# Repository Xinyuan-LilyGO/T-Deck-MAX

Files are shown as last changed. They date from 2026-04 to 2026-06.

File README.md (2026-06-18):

<h1 align = "center">🏆T-Deck-MAX 🏆</h1>

|  [中文](./readme_cn.md) |  [English](./readme.md) |
| --- | --- |

<p> 
<!-- <img src="https://img.shields.io/badge/ESP—IDF-5.1.1-ff3034" height="20px"></a> -->
</a>
</a>
</p>



| Front | Back |
| :---: | :---: |
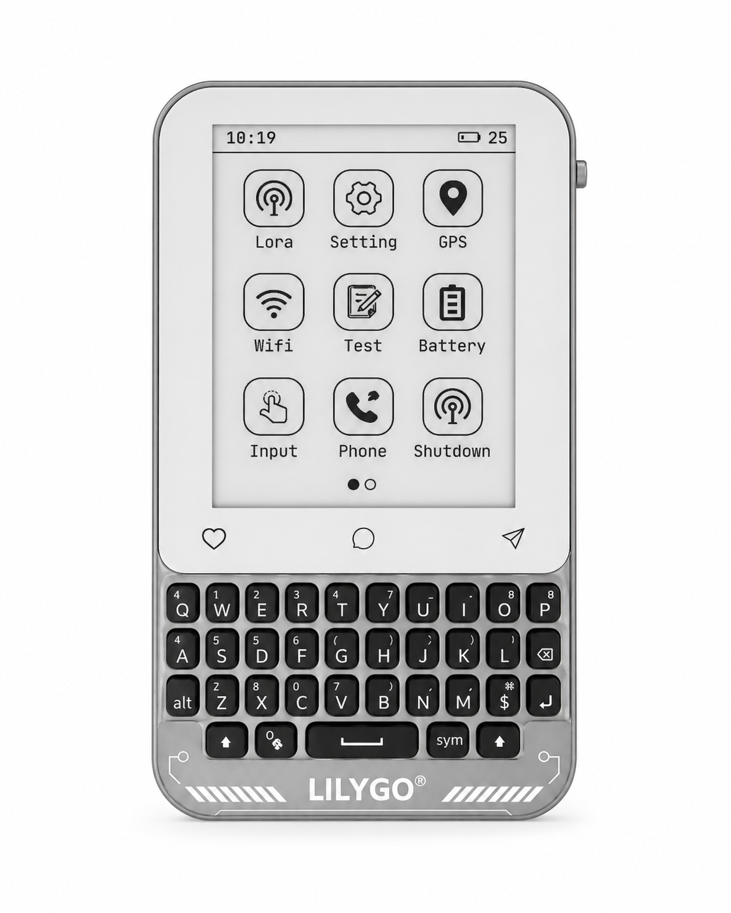
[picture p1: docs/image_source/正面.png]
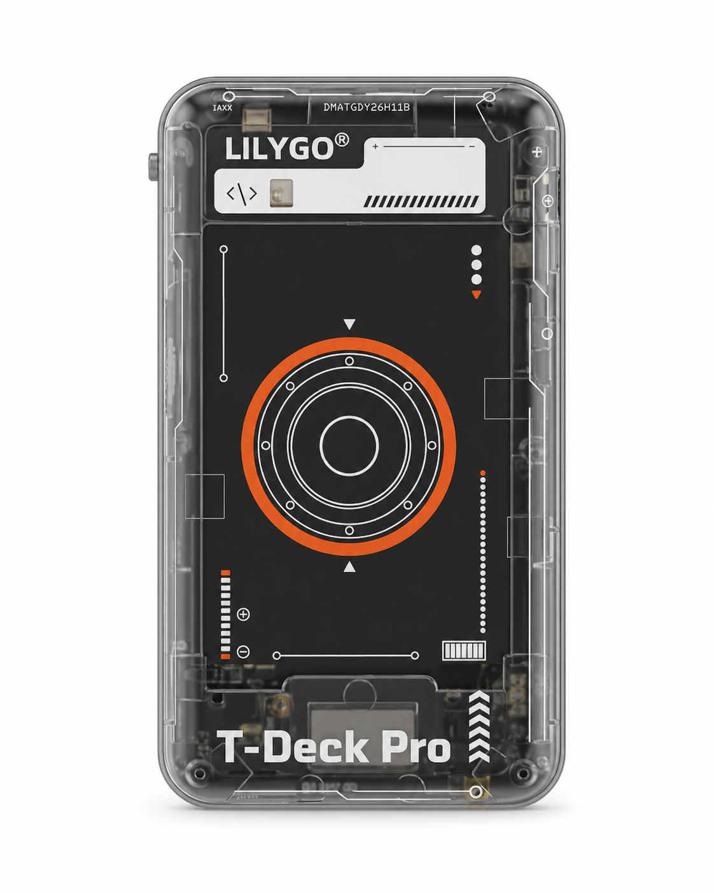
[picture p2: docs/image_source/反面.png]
|  |  |

## :zero: Version 🎁

**T-Deck-MAX** Revision Update Notes: 

- Added the XL9555 IO expansion chip 

- Remove the distinction between the audio version and the 4G version. Now, integrate the 4G (A7682E) and the audio (ES8311) onto a single board. 

- Add a LoRa antenna selection switch, controlled by XL9555 to select the internal or external antenna. The default is the internal antenna. 

- Add an audio channel output selection switch, and control the selection of using A7682E / ES8311 audio output through XL9555. 

- Add the vibration motor driving chip DRV2605

### 1、Version

How to confirm that your device is `T-Deck-MAX`?

Download the [WireScan](./firmware/examples/WireScan.bin) firmware and then open the serial port to confirm.

How to download the firmware? - [click me](./firmware/)

### 2、Where to buy.

[LilyGo Store](https://lilygo.cc/products/t-deck-pro)

## :one: Product 🎁

| Parameter | T-Deck-MAX |
| :---: | :---: |
| MCU | ESP32-S3 |
|  Flash / PSRAM | 16M / 8M |
| LoRa | SX1262 |
| GPS | MIA-M10Q |
| Display | GDEQ031T10 (320x240) |
| 4G-Module | A7682E |
| Battery Capacity | 3.7V-1400mAh |
| Battery Chip | SY6970 (0x6A), BQ27220 (0x55) |
| Audio | ES8311 (0x18) |
| Touch | CST3530 (0x1A) |
| Gyroscope | BHI260AP (0x28) |
| Keyboard | TCA8418 (0x34) |
| IO Expansion | XL9555 (0x20) |
| Motor | DRV2605 (0x5A) |

## Flashing Firmware 🎁

Before flashing firmware, connect the device to your computer, select the correct COM port, and put the board into download mode:

1. Press and hold the `BOOT` button.
2. Press and release the `RST` button on the back.
3. Release the `BOOT` button.

### 2.1. Use `LILYGO Spark` to Flash Firmware (Recommended)

- Download the tool from [LILYGO Spark](https://lilygo.cc/en-us/pages/lilygo-spark?srsltid=AfmBOoorTB7ptFu2LQNLRnoI2SA0zBGJTN6JpI9J3hmHEkKhBQSmeu0Y).

- Search for your device `T-Deck Max` and download the corresponding firmware.

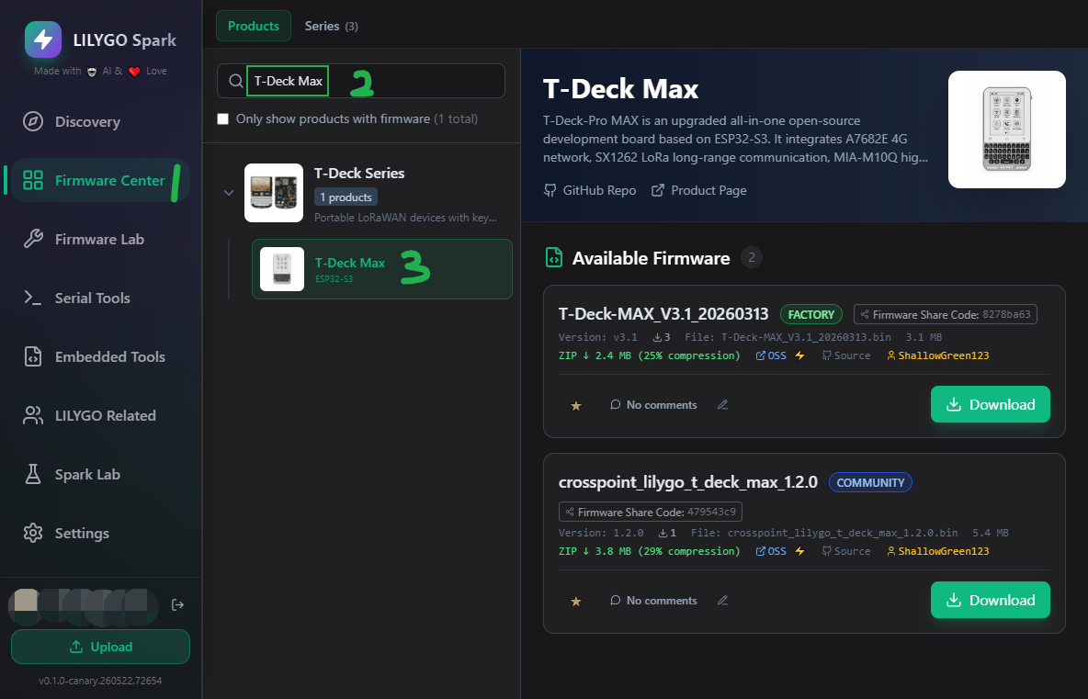
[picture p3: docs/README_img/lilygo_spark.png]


| Firmware | Note | Github |
| --- | --- | --- |
| T-Deck-MAX_xxxxx.bin | Factory program<br> | - |
| crosspoint_lilygo_t_deck_max_xxxx.bin | Reader program | [TDeckMax-Reader](https://github.com/ShallowGreen123/TDeckMax-Reader) |

## :two: Module 🎁

### 1. A7682E

A7682E https://en.simcom.com/product/A7682E.html

A7682E is the LTE Cat 1 module that supports wirelesscommunication modes of LTE-FDD/GSM/GPRS/EDGE.   It supports maximum 10Mbps downlink rate and 5Mbps uplink rate. A7682E supports multiple built-in network protocols.

Insert the SIM card and it supports calls, text messages and internet access.

Test the functionality of the A7682E using [`examples/A7682E/test_AT`](https://github.com/Xinyuan-LilyGO/T-Deck-Pro/tree/master/examples/A7682E/test_AT)

Control Via AT Commands
~~~
Frequency Bands LTE-FDD B1/B3/B5/B7/B8/B20
GSM/GPRS/EDGE 900/1800 MHz
Supply Voltage 3.4V ~ 4.2V, Typ: 3.8V
LTE Cat 1   (Uplink up to 5Mbps, Downlink up to10Mbps)
EDGE        (Uplink/Downlink up to 236.8Kbps)
GPRS        (Uplink/Downlink up to 85.6Kbps)
Firmware update via USB/FOTA
Support language calls
Support sending and receiving SMS messages
network protocols (TCP/IP/IPV4/IPV6/Multi-PDP/FTP/FTPS/HTTP/HTTPS/DNS)
RNDIS/PPP/ECM
SSL
~~~
❗ Note: The speakers of A7682E and ES8311 are shared. Set `IO12` of `XL9555` to `HIGH` and output the audio of A7682E.
The sound is too weak. Set `IO06` of the `XL9555` to `HIGH` to enable the power amplifier. [example](./examples/A7682E/test_AT/test_AT.ino)

### 2. ES8311

❗ Note: The speakers of A7682E and ES8311 are shared. Set `IO12` of `XL9555` to `LOW` and output the audio of ES8311.
The sound is too weak. Set `IO06` of the `XL9555` to `HIGH` to enable the power amplifier.

### 3. LoRa

❗ Note:
| When using the internal antenna, set `IO04` of `XL9555` to `HIGH`.<br><br>When using an external antenna, set `IO04` of `XL9555` to `LOW`.<br><br>The current repository uses `HIGH` for internal and `LOW` for external antenna selection. |
| :---------------------------------------------------------------------------------------------------------------------------------------------------------------------------------------------------------------------------------- |
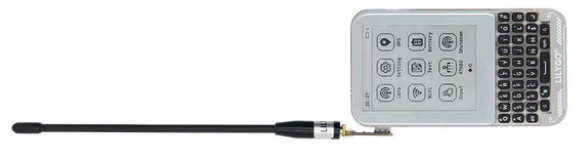
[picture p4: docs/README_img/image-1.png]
|  |

## :three: Examples 🎁

The following lists all examples to help you quickly get started with each module:

| Example | Path | Description |
| :--- | :--- | :--- |
| **WireScan** | `examples/WireScan/` | I2C device scanner, open serial monitor after flashing to verify modules |
| **test_wifi** | `examples/test_wifi/` | WiFi connection test |
| **test_BHI260AP** | `examples/test_BHI260AP/` | Gyroscope (BHI260AP) test |
| **test_GPS** | `examples/test_GPS/` | GPS (MIA-M10Q) module test |
| **keypad** | `examples/keypad/` | Keyboard input test |
| **XL9555/read** | `examples/XL9555/read/` | IO expansion chip read example |
| **XL9555/write** | `examples/XL9555/write/` | IO expansion chip write example |
| **Elink_paper/touch** | `examples/Elink_paper/touch/` | Touch screen basic test |
| **Elink_paper/display** | `examples/Elink_paper/display/` | E-paper screen display example |
| **Elink_paper/test_lvgl** | `examples/Elink_paper/test_lvgl/` | LVGL graphics library example |
| **Elink_paper/GDEQ031T10_Arduino** | `examples/Elink_paper/GDEQ031T10_Arduino/` | E-paper Arduino library driver example |
| **LoRa_sx1262/lora_send** | `examples/LoRa_sx1262/lora_send/` | LoRa send example |
| **LoRa_sx1262/lora_recv** | `examples/LoRa_sx1262/lora_recv/` | LoRa receive example |
| **A7682E/test_AT** | `examples/A7682E/test_AT/` | 4G module AT command test |
| **ES8311/playWAV** | `examples/ES8311/playWAV/` | WAV audio playback example |
| **ES8311/playFormSD** | `examples/ES8311/playFormSD/` | Audio playback from TF card example |
| **battery/bq25896** | `examples/battery/bq25896/` | Battery management IC BQ25896 test |
| **battery/bq27220** | `examples/battery/bq27220/` | Battery fuel gauge BQ27220 test |
| **battery/sy6974** | `examples/battery/sy6974/` | Battery charging IC SY6974 test |
| **motor/basic** | `examples/motor/basic/` | Vibration motor basic example |
| **motor/audio** | `examples/motor/audio/` | Vibration motor audio feedback example |
| **motor/realtime** | `examples/motor/realtime/` | Vibration motor real-time control example |
| **motor/complex** | `examples/motor/complex/` | Vibration motor complex pattern example |
| **tf_card** | `examples/tf_card/` | TF card read/write test |
| **eng_test** | `examples/eng_test/` | Full system functionality test |

### Quick Start Guide

1. **First use**: Flash `WireScan` firmware first, verify I2C communication is normal
2. **Display related**: Start with `Elink_paper/touch` or `Elink_paper/display`
3. **Wireless communication**: WiFi test uses `test_wifi`, LoRa uses `lora_send`/`lora_recv`
4. **4G communication**: Use `A7682E/test_AT` to test AT commands
5. **Audio functions**: Try `ES8311/playWAV` first to play WAV files
6. **Battery related**: Use `battery/bq25896` to check battery status

## :four: Quick Start 🎁

🟢 PlatformIO is recommended because these examples were developed on it. 🟢 

### 1、PlatformIO

1. Install [Visual Studio Code](https://code.visualstudio.com/) and [Python](https://www.python.org/), and clone or download the project;
2. Search for the `PlatformIO` plugin in the `VisualStudioCode` extension and install it;
3. After the installation is complete, you need to restart `VisualStudioCode`
4. After opening this project, PlatformIO will automatically download the required tripartite libraries and dependencies, the first time this process is relatively long, please wait patiently;
5. After all the dependencies are installed, you can open the `platformio.ini` configuration file, uncomment in `example` to select a routine, and then press `ctrl+s` to save the `.ini` configuration file;
6. Click :ballot_box_with_check: under VScode to compile the project, then plug in USB and select COM under VScode;
7. Finally, click the :arrow_right:  button to download the program to Flash;

### 2、Arduino IDE

1. Install [Arduino IDE](https://www.arduino.cc/en/software)

2. Copy all files under `this project/lib/` and paste them into the Arduino library path (generally `C:\Users\YourName\Documents\Arduino\libraries`);

3. Open the Arduino IDE and click `File->Open` in the upper left corner to open an example in `this project/example/xxx/xxx.ino` under this item;

4. Then configure Arduino. After the configuration is completed in the following way, you can click the button in the upper left corner of Arduino to compile and download;

| Arduino IDE Setting | Value                              |
| --- | --- |
| Board | ***ESP32S3 Dev Module*** |
| Port | Your port                          |
| USB CDC On Boot | Enable |
| CPU Frequency | 240MHZ(WiFi)                       |
| Core Debug Level | None                               |
| USB DFU On Boot | Disable                            |
| Erase All Flash Before Sketch Upload | Disable                            |
| Events Run On | Core1                              |
| Flash Mode | QIO 80MHZ                          |
| Flash Size | **16MB(128Mb)**                    |
| Arduino Runs On | Core1                              |
| USB Firmware MSC On Boot | Disable                            |
| Partition Scheme | **16M Flash(3M APP/9.9MB FATFS)**  |
| PSRAM | **QSPI PSRAM**                      |
| Upload Mode | **UART0/Hardware CDC**             |
| Upload Speed | 921600                             |
| USB Mode | **CDC and JTAG**                   |

## :five: Pins 🎁

Board-level macros are now centralized in a single public header:

- [`lib/TDeckMaxBoard/src/TDeckMaxBoard.h`](./lib/TDeckMaxBoard/src/TDeckMaxBoard.h)

Use it directly in examples:

~~~c
#include <TDeckMaxBoard.h>
~~~

Pin Mapping : [pinmap](./docs/pinmap.md)

## :six: Test 🎁

Sleep power consumption.

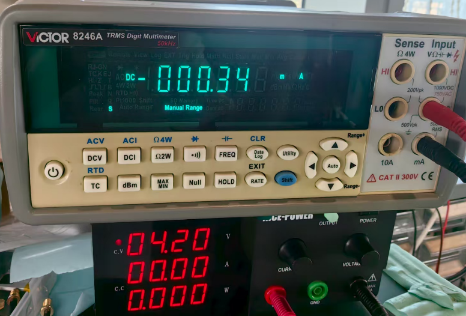
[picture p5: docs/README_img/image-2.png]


## :seven: FAQ 🎁

## :eight: Schematic & 3D 🎁

For more information, see the `./hardware` directory.

----

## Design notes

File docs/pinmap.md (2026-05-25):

# T-Deck Pro Max Pin Map (V0.1 / 2025-09-11)
> This document is organized from `hardware/T-Deck Pro Max V0.1 25-09-11/T-Deck Pro Max V0.1 25-09-11.pdf`, and cross-checked against the current repository macros in `lib/TDeckMaxBoard/src/TDeckMaxBoard.h`, `readme.md`, and `readme_cn.md`.
> It is grouped by module. Some schematic net names are labeled from the peripheral's point of view, such as `GPS_TX`, `7682_RXD`, and `I2S_DSDIN`. Where that matters, both the schematic name and the repo macro are noted.

## 1. MCU And Shared Buses

| Function | Current Macro / Preferred Name | GPIO | Source | Notes |
| --- | --- | --- | --- | --- |
| Shared I2C SDA | `BOARD_I2C_SDA` | 13 | Schematic Page 1/4/7/8 | Shared by the main board I2C bus |
| Shared I2C SCL | `BOARD_I2C_SCL` | 14 | Schematic Page 1/4/7/8 | Shared by the main board I2C bus |
| Shared SPI SCK | `BOARD_SPI_SCK` | 36 | Schematic Page 3/4/6 | Shared by EPD, TF, and SX1262 |
| Shared SPI MOSI | `BOARD_SPI_MOSI` | 33 | Schematic Page 3/4/6 | Shared by EPD, TF, and SX1262 |
| Shared SPI MISO | `BOARD_SPI_MISO` | 47 | Schematic Page 3/6 | Shared by TF and SX1262 |
| BOOT | `BOARD_BOOT_PIN` | 0 | Schematic Page 2 | Boot button |

## 2. XL9555 Expansion IO

I2C address: `0x20`.

`BOARD_XL9555_INT` is currently fixed to `-1`, because the XL9555 `INT` pin is not connected to any ESP32-S3 pin.

| XL9555 | Current Macro / Preferred Name | Board Net | Direction | Source | Notes |
| --- | --- | --- | --- | --- | --- |
| P00 | `BOARD_XL9555_00_6609_EN` | `6609_EN` | Output | Schematic Page 1/7 | Enables A7682E power |
| P01 | `BOARD_XL9555_01_LORA_EN` | `LORA_EN` | Output | Schematic Page 3/7 | Enables SX1262 power |
| P02 | `BOARD_XL9555_02_GPS_EN` | `GPS_EN` | Output | Schematic Page 3/7 | Enables MIA-M10Q power |
| P03 | `BOARD_XL9555_03_1V8_EN` | `1V8_EN` | Output | Schematic Page 4/7 | Enables BHI260AP 1.8 V rail |
| P04 | `BOARD_XL9555_04_LORA_SEL` | `LORA_SEL` | Output | Schematic Page 3/7 | `HIGH` = internal antenna, `LOW` = external antenna |
| P05 | `BOARD_XL9555_05_MOTOR_EN` | `M_EN` | Output | Schematic Page 4/7 | DRV2605 power / enable |
| P06 | `BOARD_XL9555_06_AMPLIFIER` | `SHUTDOWM` | Output | Schematic Page 7/8 | Power amplifier enable; the schematic net is spelled `SHUTDOWM` |
| P07 | `BOARD_XL9555_07_TOUCH_RST` | `T_RST` | Output | Schematic Page 4/7 | Touch reset, active low |
| P10 | `BOARD_XL9555_10_PWRKEY_EN` | `PWRKEY_EN` | Output | Schematic Page 5/7 | A7682E `PWRKEY` control |
| P11 | `BOARD_XL9555_11_KEY_RST` | `KEY_RST` | Output | Schematic Page 7 | Keyboard reset, active low |
| P12 | `BOARD_XL9555_12_AUDIO_SEL` | `AUDIO_SEL` | Output | Schematic Page 7/8 | `HIGH = A7682E`, `LOW = ES8311` |
| P13 | `BOARD_XL9555_13` | NC | - | Schematic Page 7 | Reserved in the current repo |
| P14 | `BOARD_XL9555_14` | NC | - | Schematic Page 7 | Reserved in the current repo |
| P15 | `BOARD_XL9555_15` | NC | - | Schematic Page 7 | Reserved in the current repo |
| P16 | `BOARD_XL9555_16` | NC | - | Schematic Page 7 | Reserved in the current repo |
| P17 | `BOARD_XL9555_17` | NC | - | Schematic Page 7 | Reserved in the current repo |

## 3. EPD Display

| Function | Current Macro / Preferred Name | GPIO / Mapping | Source | Notes |
| --- | --- | --- | --- | --- |
| EPD DC | `BOARD_EPD_DC` | GPIO35 | Schematic Page 4 | Schematic net name: `LCD_D/C` |
| EPD CS | `BOARD_EPD_CS` | GPIO34 | Schematic Page 4 | Schematic net name: `LCD_CS` |
| EPD BUSY | `BOARD_EPD_BUSY` | GPIO37 | Schematic Page 4 | Schematic net name: `LCD_BUSY` |
| EPD RST | `BOARD_EPD_RST` | GPIO9 | Schematic Page 4 | Schematic net name: `LCD_RST` |
| EPD SCK | `BOARD_EPD_SCK` | GPIO36 | Schematic Page 4 | Shared SPI bus |
| EPD MOSI | `BOARD_EPD_MOSI` | GPIO33 | Schematic Page 4 | Shared SPI bus |
| EPD frontlight PWM | `BOARD_EPD_BL` | GPIO41 | Schematic Page 4 | Schematic net name: `BL_PWM` |

## 4. Touch CST328

I2C address: `0x1A`.

| Function | Current Macro / Preferred Name | GPIO / Mapping | Source | Notes |
| --- | --- | --- | --- | --- |
| I2C SDA | `BOARD_TOUCH_SDA` | GPIO13 | Schematic Page 4 | Shared I2C bus |
| I2C SCL | `BOARD_TOUCH_SCL` | GPIO14 | Schematic Page 4 | Shared I2C bus |
| INT | `BOARD_TOUCH_INT` | GPIO12 | Schematic Page 4 | CST328 interrupt |
| RST | `BOARD_TOUCH_RST` | `XL9555 P07` | Schematic Page 4/7 | Board net `T_RST`; not a direct ESP32 GPIO |

## 5. Keyboard TCA8418

I2C address: `0x34`.

| Function | Current Macro / Preferred Name | GPIO / Mapping | Source | Notes |
| --- | --- | --- | --- | --- |
| I2C SDA | `BOARD_KEYBOARD_SDA` | GPIO13 | Schematic Page 7 | Shared I2C bus |
| I2C SCL | `BOARD_KEYBOARD_SCL` | GPIO14 | Schematic Page 7 | Shared I2C bus |
| INT | `BOARD_KEYBOARD_INT` | GPIO15 | Schematic Page 7 | TCA8418 interrupt |
| Backlight PWM | `BOARD_KEYBOARD_LED` | GPIO42 | Schematic Page 7 | Schematic net name: `LED_PWM` |
| RST | `BOARD_KEYBOARD_RST` | `XL9555 P11` | Schematic Page 7 | Board net `KEY_RST`, active low |

## 6. IMU BHI260AP

I2C address: `0x28`.

| Function | Current Macro / Preferred Name | GPIO / Mapping | Source | Notes |
| --- | --- | --- | --- | --- |
| I2C SDA | `BOARD_GYROSCOPDE_SDA` | GPIO13 | Schematic Page 4 | Shared I2C bus |
| I2C SCL | `BOARD_GYROSCOPDE_SCL` | GPIO14 | Schematic Page 4 | Shared I2C bus |
| INT | `BOARD_GYROSCOPDE_INT` | GPIO21 | Schematic Page 4 | Schematic net name: `HIRQ` |
| RST | `BOARD_GYROSCOPDE_RST` | `-1` | Schematic Page 4 | Reset is not wired |
| Power enable | `BOARD_XL9555_03_1V8_EN` | `XL9555 P03` | Schematic Page 4/7 | `HIGH` powers the IMU rail |

## 7. Motor DRV2605

I2C address: `0x5A`.

| Function | Current Macro / Preferred Name | GPIO / Mapping | Source | Notes |
| --- | --- | --- | --- | --- |
| I2C SDA | `BOARD_MOTOR_SDA` | GPIO13 | Schematic Page 4 | Shared I2C bus |
| I2C SCL | `BOARD_MOTOR_SCL` | GPIO14 | Schematic Page 4 | Shared I2C bus |
| Power / enable | `BOARD_MOTOR_EN` | `XL9555 P05` | Schematic Page 4/7 | Board net `M_EN` |

## 8. LoRa SX1262

| Function | Current Macro / Preferred Name | GPIO / Mapping | Source | Notes |
| --- | --- | --- | --- | --- |
| SCK | `BOARD_LORA_SCK` | GPIO36 | Schematic Page 3 | Shared SPI bus |
| MOSI | `BOARD_LORA_MOSI` | GPIO33 | Schematic Page 3 | Shared SPI bus |
| MISO | `BOARD_LORA_MISO` | GPIO47 | Schematic Page 3 | Shared SPI bus |
| CS | `BOARD_LORA_CS` | GPIO3 | Schematic Page 3 | Module `NSS` |
| RST | `BOARD_LORA_RST` | GPIO4 | Schematic Page 3 | Module `NRESET` |
| IRQ | `BOARD_LORA_INT` | GPIO5 | Schematic Page 3 | Module `DIO1` |
| BUSY | `BOARD_LORA_BUSY` | GPIO6 | Schematic Page 3 | Module `BUSY` |
| Power enable | `BOARD_XL9555_01_LORA_EN` | `XL9555 P01` | Schematic Page 3/7 | `HIGH` powers the module |
| Antenna select | `BOARD_XL9555_04_LORA_SEL` | `XL9555 P04` | Schematic Page 3/7 | Current repo convention: `HIGH` = internal, `LOW` = external |

## 9. GPS MIA-M10Q

| Function | Current Macro / Preferred Name | GPIO / Mapping | Source | Notes |
| --- | --- | --- | --- | --- |
| PPS | `BOARD_GPS_PPS` | GPIO1 | Schematic Page 3 | Schematic net name: `PPS` |
| Module TX -> MCU RX | `GPS_TX` / `BOARD_GPS_RXD` | GPIO2 | Schematic Page 3 | Schematic net names are from the GPS module point of view |
| Module RX <- MCU TX | `GPS_RX` / `BOARD_GPS_TXD` | GPIO16 | Schematic Page 3 | Schematic net names are from the GPS module point of view |
| Power enable | `BOARD_XL9555_02_GPS_EN` | `XL9555 P02` | Schematic Page 3/7 | `HIGH` powers the module |

## 10. 4G Modem A7682E

| Function | Current Macro / Preferred Name | GPIO / Mapping | Source | Notes |
| --- | --- | --- | --- | --- |
| RI | `BOARD_A7682E_RI` | GPIO7 | Schematic Page 2/5 | Module `RI` |
| DTR | `BOARD_A7682E_ITR` / `BOARD_A7682E_DTR` | GPIO8 | Schematic Page 2/5 | The current repo interprets this signal as `DTR` |
| Module RXD | `7682_RXD` / `BOARD_A7682E_RXD` | GPIO10 | Schematic Page 2/5 | Net name is labeled from the modem side |
| Module TXD | `7682_TXD` / `BOARD_A7682E_TXD` | GPIO11 | Schematic Page 2/5 | Net name is labeled from the modem side |
| Power enable | `BOARD_XL9555_00_6609_EN` | `XL9555 P00` | Schematic Page 1/7 | A7682E main power rail enable |
| `PWRKEY` control | `BOARD_A7682E_PWRKEY` / `BOARD_XL9555_10_PWRKEY_EN` | `XL9555 P10` | Schematic Page 5/7 | Board net `PWRKEY_EN` |

## 11. TF Card

| Function | Current Macro / Preferred Name | GPIO | Source | Notes |
| --- | --- | --- | --- | --- |
| SD CS | `BOARD_SD_CS` | 48 | Schematic Page 2/6 | Shares SPI with EPD and LoRa |
| SD SCK | `BOARD_SD_SCK` | 36 | Schematic Page 3/6 | Shared SPI bus |
| SD MOSI | `BOARD_SD_MOSI` | 33 | Schematic Page 3/6 | Shared SPI bus |
| SD MISO | `BOARD_SD_MISO` | 47 | Schematic Page 3/6 | Shared SPI bus |

## 12. Audio ES8311

I2C address: `0x18`.

| Function | Current Macro / Preferred Name | GPIO / Mapping | Source | Notes |
| --- | --- | --- | --- | --- |
| I2C SDA | `BOARD_ES8311_SDA` | GPIO13 | Schematic Page 8 | Shared I2C bus |
| I2C SCL | `BOARD_ES8311_SCL` | GPIO14 | Schematic Page 8 | Shared I2C bus |
| I2S MCLK | `BOARD_ES8311_MCLK` | GPIO38 | Schematic Page 8 | `I2S_MCLK` |
| I2S BCLK / SCLK | `BOARD_ES8311_SCLK` | GPIO39 | Schematic Page 8 | `I2S_SCLK` |
| I2S LRCK | `BOARD_ES8311_LRCK` | GPIO18 | Schematic Page 8 | `I2S_LRCK` |
| ES8311 `ASDOUT` -> ESP32 DIN | `BOARD_ES8311_ASDOUT` | GPIO40 | Schematic Page 8 | Current repo macro naming follows the existing code convention |
| ESP32 DOUT -> ES8311 `DSDIN` | `BOARD_ES8311_DSDIN` | GPIO17 | Schematic Page 8 | Current repo macro naming follows the existing code convention |
| Power amp enable | `BOARD_XL9555_06_AMPLIFIER` | `XL9555 P06` | Schematic Page 7/8 | `HIGH` enables the amplifier |
| Audio route select | `BOARD_XL9555_12_AUDIO_SEL` | `XL9555 P12` | Schematic Page 7/8 | `HIGH = A7682E`, `LOW = ES8311` |

> Note: the current repo uses the long-standing `BOARD_ES8311_ASDOUT/DSDIN` macro names from the code side. If you read the ES8311 pin names strictly from the codec side, the apparent data directions can look reversed, so always verify the signal direction when refactoring or wiring new code.

## 13. I2C Address Table

| Device | Address | Source | Notes |
| --- | --- | --- | --- |
| ES8311 | `0x18` | Schematic Page 8 | Audio codec |
| CST328 | `0x1A` | `readme*.md` | Touch controller |
| XL9555 | `0x20` | Schematic Page 7 | IO expander |
| BHI260AP | `0x28` | Schematic Page 4 | IMU |
| TCA8418 | `0x34` | Schematic Page 7 | Keyboard matrix controller |
| BQ27220 | `0x55` | Schematic Page 1 | Fuel gauge |
| DRV2605 | `0x5A` | Schematic Page 4 | Vibration motor driver |
| BQ25896 | `0x6B` | Schematic Page 1 | Charger, now deprecated |
| SY6970 | `0x6A` | Schematic Page 1 | Charger |

Note: `BQ25896` was later replaced. Newer `T-Deck-MAX` boards use `SY6970`.

## 14. Current Codebase Notes

- `BOARD_A7682E_ITR` should be understood as `DTR`. The current public header also provides the alias `BOARD_A7682E_DTR`.
- GPS UART, A7682E UART, and ES8311 I2S naming still mix peripheral-side and ESP32-side viewpoints in different places. When writing new code, spell out the direction explicitly.
- Board-level macros are now centralized in `lib/TDeckMaxBoard/src/TDeckMaxBoard.h`.

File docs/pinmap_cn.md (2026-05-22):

# T-Deck Pro Max 引脚映射（V0.1 / 2025-09-11）

> 本文按 `hardware/T-Deck Pro Max V0.1 25-09-11/T-Deck Pro Max V0.1 25-09-11.pdf` 整理，并交叉核对了仓库当前 `readme.md`、`readme_cn.md` 与 `examples/factory/utilities.h`。

> 本文按模块分类整理。原理图里部分网络名按外设视角命名，例如 `GPS_TX`、`7682_RXD`、`I2S_DSDIN`；文中会同时注明仓库里常见的板级宏名。

## 1. 主控与公共总线

| 功能 | 当前宏/建议名 | GPIO | 来源 | 备注 |
| --- | --- | --- | --- | --- |
| 主 I2C SDA | `BOARD_I2C_SDA` | 13 | 原理图 Page 1/4/7/8 | 全板共享 I2C |
| 主 I2C SCL | `BOARD_I2C_SCL` | 14 | 原理图 Page 1/4/7/8 | 全板共享 I2C |
| 主 SPI SCK | `BOARD_SPI_SCK` | 36 | 原理图 Page 3/4/6 | EPD、TF、SX1262 共用 |
| 主 SPI MOSI | `BOARD_SPI_MOSI` | 33 | 原理图 Page 3/4/6 | EPD、TF、SX1262 共用 |
| 主 SPI MISO | `BOARD_SPI_MISO` | 47 | 原理图 Page 3/6 | TF、SX1262 共用 |
| BOOT | `BOARD_BOOT_PIN` | 0 | 原理图 Page 2 | 启动按键 |

## 2. XL9555 扩展 IO

I2C 地址：`0x20`。

`BOARD_XL9555_INT` 当前固定为 `-1`，因为 XL9555 的 `INT` 没有接入任何 ESP32 引脚。

| XL9555 | 当前宏/建议名 | 板级网络 | 方向 | 来源 | 备注 |
| --- | --- | --- | --- | --- | --- |
| P00 | `BOARD_XL9555_00_6609_EN` | `6609_EN` | 输出 | 原理图 Page 1/7 | A7682E 电源使能 |
| P01 | `BOARD_XL9555_01_LORA_EN` | `LORA_EN` | 输出 | 原理图 Page 3/7 | SX1262 电源使能 |
| P02 | `BOARD_XL9555_02_GPS_EN` | `GPS_EN` | 输出 | 原理图 Page 3/7 | MIA-M10Q 电源使能 |
| P03 | `BOARD_XL9555_03_1V8_EN` | `1V8_EN` | 输出 | 原理图 Page 4/7 | BHI260AP 1.8 V 电源使能 |
| P04 | `BOARD_XL9555_04_LORA_SEL` | `LORA_SEL` | 输出 | 原理图 Page 3/7 | `HIGH` 内置天线，`LOW` 外置天线 |
| P05 | `BOARD_XL9555_05_MOTOR_EN` | `M_EN` | 输出 | 原理图 Page 4/7 | DRV2605 供电/使能 |
| P06 | `BOARD_XL9555_06_AMPLIFIER` | `SHUTDOWM` | 输出 | 原理图 Page 7/8 | 功放使能；原理图网名拼写就是 `SHUTDOWM` |
| P07 | `BOARD_XL9555_07_TOUCH_RST` | `T_RST` | 输出 | 原理图 Page 4/7 | 触摸复位，低有效 |
| P10 | `BOARD_XL9555_10_PWRKEY_EN` | `PWRKEY_EN` | 输出 | 原理图 Page 5/7 | A7682E `PWRKEY` 控制 |
| P11 | `BOARD_XL9555_11_KEY_RST` | `KEY_RST` | 输出 | 原理图 Page 7 | 键盘复位，低有效 |
| P12 | `BOARD_XL9555_12_AUDIO_SEL` | `AUDIO_SEL` | 输出 | 原理图 Page 7/8 | `HIGH = A7682E`，`LOW = ES8311` |
| P13 | `BOARD_XL9555_13` | NC | - | 原理图 Page 7 | 当前仓库保留 |
| P14 | `BOARD_XL9555_14` | NC | - | 原理图 Page 7 | 当前仓库保留 |
| P15 | `BOARD_XL9555_15` | NC | - | 原理图 Page 7 | 当前仓库保留 |
| P16 | `BOARD_XL9555_16` | NC | - | 原理图 Page 7 | 当前仓库保留 |
| P17 | `BOARD_XL9555_17` | NC | - | 原理图 Page 7 | 当前仓库保留 |

## 3. EPD 显示

| 功能 | 当前宏/建议名 | GPIO/映射 | 来源 | 备注 |
| --- | --- | --- | --- | --- |
| EPD DC | `BOARD_EPD_DC` | GPIO35 | 原理图 Page 4 | 原理图网络名 `LCD_D/C` |
| EPD CS | `BOARD_EPD_CS` | GPIO34 | 原理图 Page 4 | 原理图网络名 `LCD_CS` |
| EPD BUSY | `BOARD_EPD_BUSY` | GPIO37 | 原理图 Page 4 | 原理图网络名 `LCD_BUSY` |
| EPD RST | `BOARD_EPD_RST` | GPIO9 | 原理图 Page 4 | 原理图网络名 `LCD_RST` |
| EPD SCK | `BOARD_EPD_SCK` | GPIO36 | 原理图 Page 4 | 共用主 SPI |
| EPD MOSI | `BOARD_EPD_MOSI` | GPIO33 | 原理图 Page 4 | 共用主 SPI |
| EPD 前光 PWM | `BOARD_EPD_BL` | GPIO41 | 原理图 Page 4 | 原理图网络名 `BL_PWM` |

## 4. 触摸 CST328

I2C 地址：`0x1A`。

| 功能 | 当前宏/建议名 | GPIO/映射 | 来源 | 备注 |
| --- | --- | --- | --- | --- |
| I2C SDA | `BOARD_TOUCH_SDA` | GPIO13 | 原理图 Page 4 | 共用主 I2C |
| I2C SCL | `BOARD_TOUCH_SCL` | GPIO14 | 原理图 Page 4 | 共用主 I2C |
| INT | `BOARD_TOUCH_INT` | GPIO12 | 原理图 Page 4 | CST328 中断 |
| RST | `BOARD_TOUCH_RST` | `XL9555 P07` | 原理图 Page 4/7 | 板级网络 `T_RST`，不是 ESP32 直连 GPIO |

## 5. 键盘 TCA8418

I2C 地址：`0x34`。

| 功能 | 当前宏/建议名 | GPIO/映射 | 来源 | 备注 |
| --- | --- | --- | --- | --- |
| I2C SDA | `BOARD_KEYBOARD_SDA` | GPIO13 | 原理图 Page 7 | 共用主 I2C |
| I2C SCL | `BOARD_KEYBOARD_SCL` | GPIO14 | 原理图 Page 7 | 共用主 I2C |
| INT | `BOARD_KEYBOARD_INT` | GPIO15 | 原理图 Page 7 | TCA8418 中断 |
| 背光 PWM | `BOARD_KEYBOARD_LED` | GPIO42 | 原理图 Page 7 | 原理图网络名 `LED_PWM` |
| RST | `BOARD_KEYBOARD_RST` | `XL9555 P11` | 原理图 Page 7 | 板级网络 `KEY_RST`，低有效 |

## 6. IMU BHI260AP

I2C 地址：`0x28`。

| 功能 | 当前宏/建议名 | GPIO/映射 | 来源 | 备注 |
| --- | --- | --- | --- | --- |
| I2C SDA | `BOARD_GYROSCOPDE_SDA` | GPIO13 | 原理图 Page 4 | 共用主 I2C |
| I2C SCL | `BOARD_GYROSCOPDE_SCL` | GPIO14 | 原理图 Page 4 | 共用主 I2C |
| INT | `BOARD_GYROSCOPDE_INT` | GPIO21 | 原理图 Page 4 | 原理图网络名 `HIRQ` |
| RST | `BOARD_GYROSCOPDE_RST` | `-1` | 原理图 Page 4 | 当前未接复位脚 |
| 电源使能 | `BOARD_XL9555_03_1V8_EN` | `XL9555 P03` | 原理图 Page 4/7 | `HIGH` 上电 |

## 7. 马达 DRV2605

I2C 地址：`0x5A`。

| 功能 | 当前宏/建议名 | GPIO/映射 | 来源 | 备注 |
| --- | --- | --- | --- | --- |
| I2C SDA | `BOARD_MOTOR_SDA` | GPIO13 | 原理图 Page 4 | 共用主 I2C |
| I2C SCL | `BOARD_MOTOR_SCL` | GPIO14 | 原理图 Page 4 | 共用主 I2C |
| 供电/使能 | `BOARD_MOTOR_EN` | `XL9555 P05` | 原理图 Page 4/7 | 板级网络 `M_EN` |

## 8. LoRa SX1262

| 功能 | 当前宏/建议名 | GPIO/映射 | 来源 | 备注 |
| --- | --- | --- | --- | --- |
| SCK | `BOARD_LORA_SCK` | GPIO36 | 原理图 Page 3 | 共用主 SPI |
| MOSI | `BOARD_LORA_MOSI` | GPIO33 | 原理图 Page 3 | 共用主 SPI |
| MISO | `BOARD_LORA_MISO` | GPIO47 | 原理图 Page 3 | 共用主 SPI |
| CS | `BOARD_LORA_CS` | GPIO3 | 原理图 Page 3 | 模块 `NSS` |
| RST | `BOARD_LORA_RST` | GPIO4 | 原理图 Page 3 | 模块 `NRESET` |
| IRQ | `BOARD_LORA_INT` | GPIO5 | 原理图 Page 3 | 模块 `DIO1` |
| BUSY | `BOARD_LORA_BUSY` | GPIO6 | 原理图 Page 3 | 模块 `BUSY` |
| 电源使能 | `BOARD_XL9555_01_LORA_EN` | `XL9555 P01` | 原理图 Page 3/7 | `HIGH` 上电 |
| 天线切换 | `BOARD_XL9555_04_LORA_SEL` | `XL9555 P04` | 原理图 Page 3/7 | 当前仓库以 `HIGH` 内置、`LOW` 外置 为准 |

## 9. GPS MIA-M10Q

| 功能 | 当前宏/建议名 | GPIO/映射 | 来源 | 备注 |
| --- | --- | --- | --- | --- |
| PPS | `BOARD_GPS_PPS` | GPIO1 | 原理图 Page 3 | 原理图网络名 `PPS` |
| 模块 TX -> 主控 RX | `GPS_TX` / `BOARD_GPS_RXD` | GPIO2 | 原理图 Page 3 | 原理图网名按 GPS 模块视角命名 |
| 模块 RX <- 主控 TX | `GPS_RX` / `BOARD_GPS_TXD` | GPIO16 | 原理图 Page 3 | 原理图网名按 GPS 模块视角命名 |
| 电源使能 | `BOARD_XL9555_02_GPS_EN` | `XL9555 P02` | 原理图 Page 3/7 | `HIGH` 上电 |

## 10. 4G 模块 A7682E

| 功能 | 当前宏/建议名 | GPIO/映射 | 来源 | 备注 |
| --- | --- | --- | --- | --- |
| RI | `BOARD_A7682E_RI` | GPIO7 | 原理图 Page 2/5 | 模块 `RI` |
| DTR | `BOARD_A7682E_ITR` | GPIO8 | 原理图 Page 2/5 | 当前仓库把这个宏理解为 `DTR` |
| 模块 RXD | `7682_RXD` / `BOARD_A7682E_RXD` | GPIO10 | 原理图 Page 2/5 | 网名按模块视角命名 |
| 模块 TXD | `7682_TXD` / `BOARD_A7682E_TXD` | GPIO11 | 原理图 Page 2/5 | 网名按模块视角命名 |
| 电源使能 | `BOARD_XL9555_00_6609_EN` | `XL9555 P00` | 原理图 Page 1/7 | A7682E 电源域 |
| `PWRKEY` 控制 | `BOARD_A7682E_PWRKEY` / `BOARD_XL9555_10_PWRKEY_EN` | `XL9555 P10` | 原理图 Page 5/7 | 板级网络 `PWRKEY_EN` |

## 11. TF 卡

| 功能 | 当前宏/建议名 | GPIO | 来源 | 备注 |
| --- | --- | --- | --- | --- |
| SD CS | `BOARD_SD_CS` | 48 | 原理图 Page 2/6 | 与 EPD、LoRa 共用 SPI |
| SD SCK | `BOARD_SD_SCK` | 36 | 原理图 Page 3/6 | 共用主 SPI |
| SD MOSI | `BOARD_SD_MOSI` | 33 | 原理图 Page 3/6 | 共用主 SPI |
| SD MISO | `BOARD_SD_MISO` | 47 | 原理图 Page 3/6 | 共用主 SPI |

## 12. 音频 ES8311

I2C 地址：`0x18`。

| 功能 | 当前宏/建议名 | GPIO/映射 | 来源 | 备注 |
| --- | --- | --- | --- | --- |
| I2C SDA | `BOARD_ES8311_SDA` | GPIO13 | 原理图 Page 8 | 共用主 I2C |
| I2C SCL | `BOARD_ES8311_SCL` | GPIO14 | 原理图 Page 8 | 共用主 I2C |
| I2S MCLK | `BOARD_ES8311_MCLK` | GPIO38 | 原理图 Page 8 | `I2S_MCLK` |
| I2S BCLK/SCLK | `BOARD_ES8311_SCLK` | GPIO39 | 原理图 Page 8 | `I2S_SCLK` |
| I2S LRCK | `BOARD_ES8311_LRCK` | GPIO18 | 原理图 Page 8 | `I2S_LRCK` |
| ES8311 `ASDOUT` -> ESP32 DIN | 原理图网名 `I2S_ASDOUT` | GPIO40 | 原理图 Page 8 | 原理图按 esp32 视角命名 |
| ESP32 DOUT -> ES8311 `DSDIN` | 原理图网名 `I2S_DSDIN` | GPIO17 | 原理图 Page 8 | 原理图按 esp32 视角命名 |
| 功放使能 | `BOARD_XL9555_06_AMPLIFIER` | `XL9555 P06` | 原理图 Page 7/8 | `HIGH` 使能 |
| 音频路由选择 | `BOARD_XL9555_12_AUDIO_SEL` | `XL9555 P12` | 原理图 Page 7/8 | `HIGH = A7682E`，`LOW = ES8311` |

> 说明：`readme*.md` 与 `examples/factory/utilities.h` 中的 `BOARD_ES8311_ASDOUT/DSDIN` 用的是 ESP32 I2S 方向命名；如果按原理图网名理解，则应对应 `ASDOUT = GPIO17`、`DSDIN = GPIO40`。

## 13. I2C 地址表

| 设备 | 地址 | 来源 | 备注 |
| --- | --- | --- | --- |
| ES8311 | `0x18` | 原理图 Page 8 | 音频 codec |
| CST328 | `0x1A` | `readme*.md` | 触摸控制器 |
| XL9555 | `0x20` | 原理图 Page 7 | IO 扩展 |
| BHI260AP | `0x28` | 原理图 Page 4 | IMU |
| TCA8418 | `0x34` | 原理图 Page 7 | 键盘矩阵控制器 |
| BQ27220 | `0x55` | 原理图 Page 1 | 电量计 |
| DRV2605 | `0x5A` | 原理图 Page 4 | 振动马达驱动 |
| BQ25896 | `0x6B` | 原理图 Page 1 | 充电管理(已停用) |
| SY6970 | `0x6A` | 原理图 Page 1 | 充电管理 |

说明：`BQ25896` 因为一些原因停用，后续的 `T-Deck-MAX` 都将使用 `SY6970`。

## 14. 代码现状提示

- `BOARD_A7682E_ITR` 这个宏名在当前仓库里应理解为 `DTR`。
- GPS、A7682E UART、ES8311 I2S 这三组信号，代码里同时存在“外设网名视角”和“ESP32 侧视角”两套叫法，写新代码时最好把方向写清楚。
- 当前仓库的主板宏主要散落在 `readme*.md`、`examples/factory/utilities.h` 和若干示例各自的 `utilities.h`，建议后续收敛成单一公共头文件。

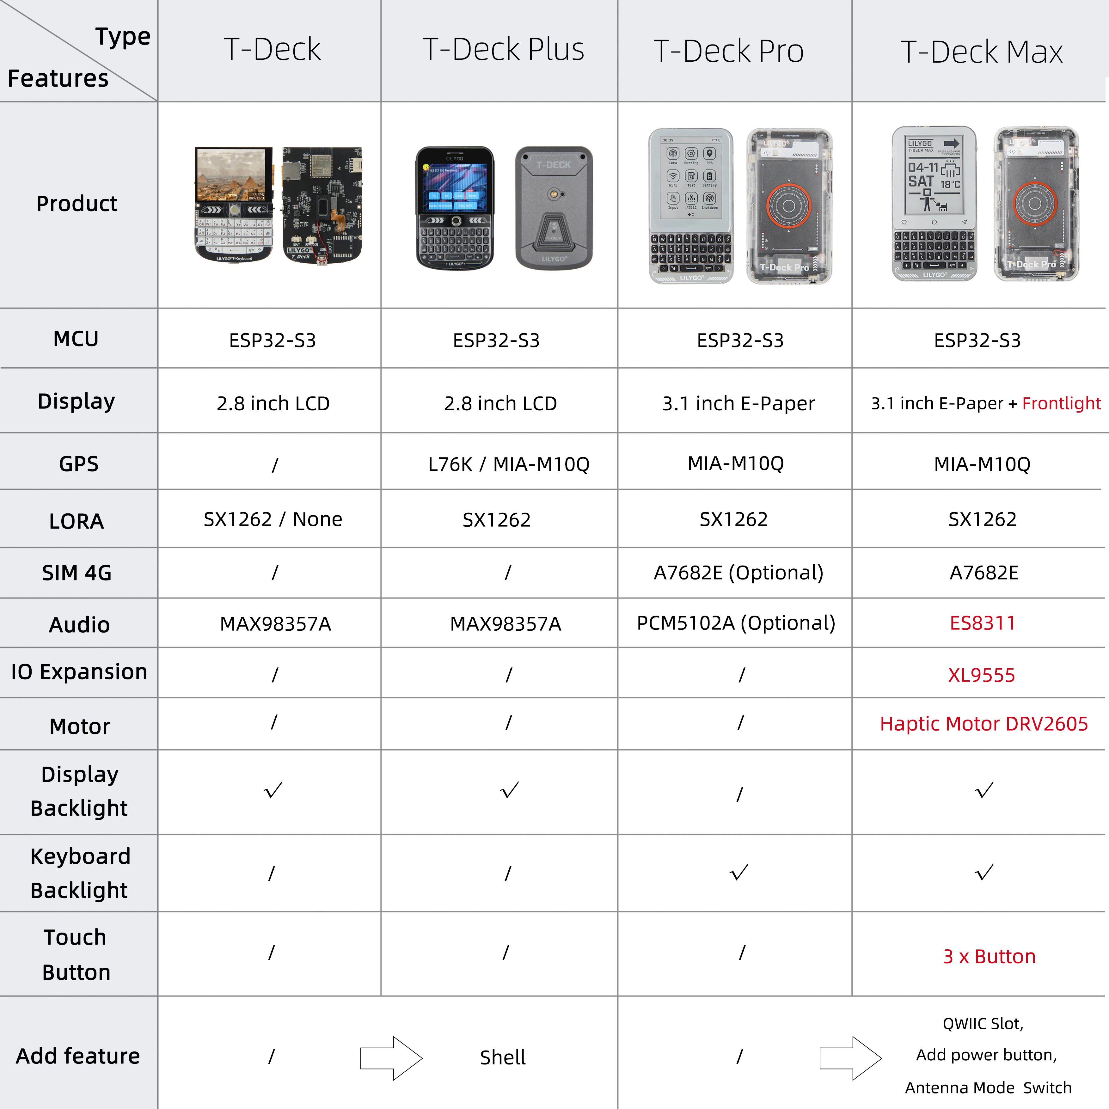
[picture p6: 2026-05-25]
hardware/Comparison .jpg

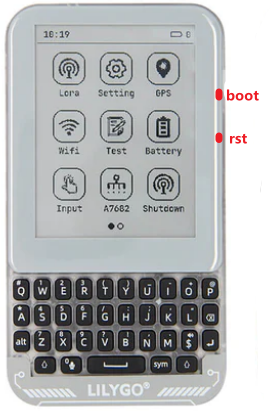
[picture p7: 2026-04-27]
docs/firmware_dowmload/image.png

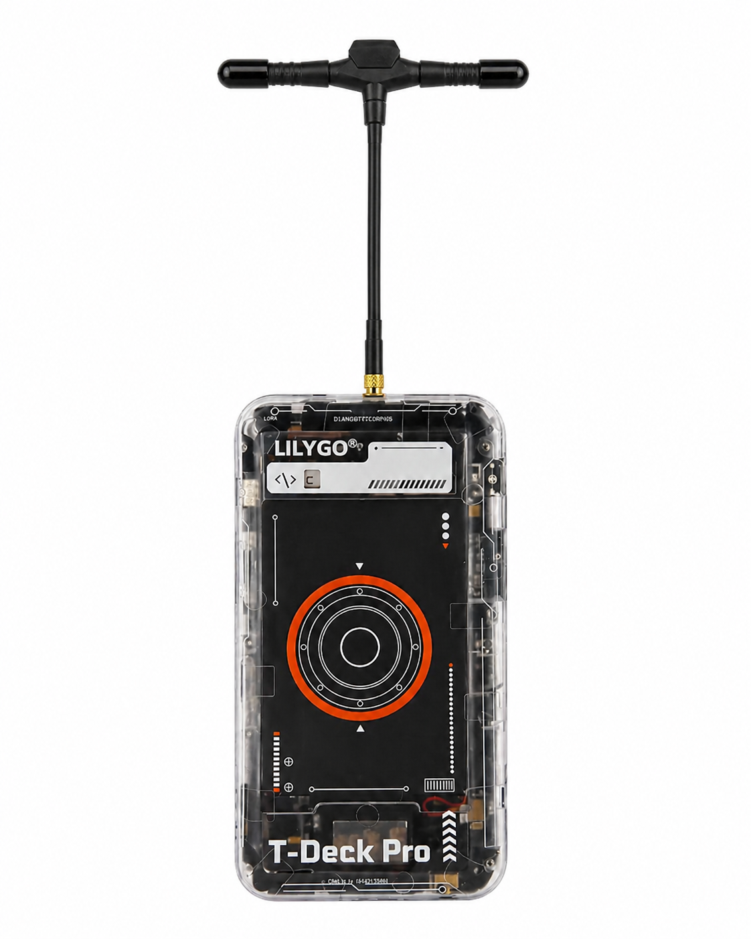
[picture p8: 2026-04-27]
docs/image_source/反面_天线.png

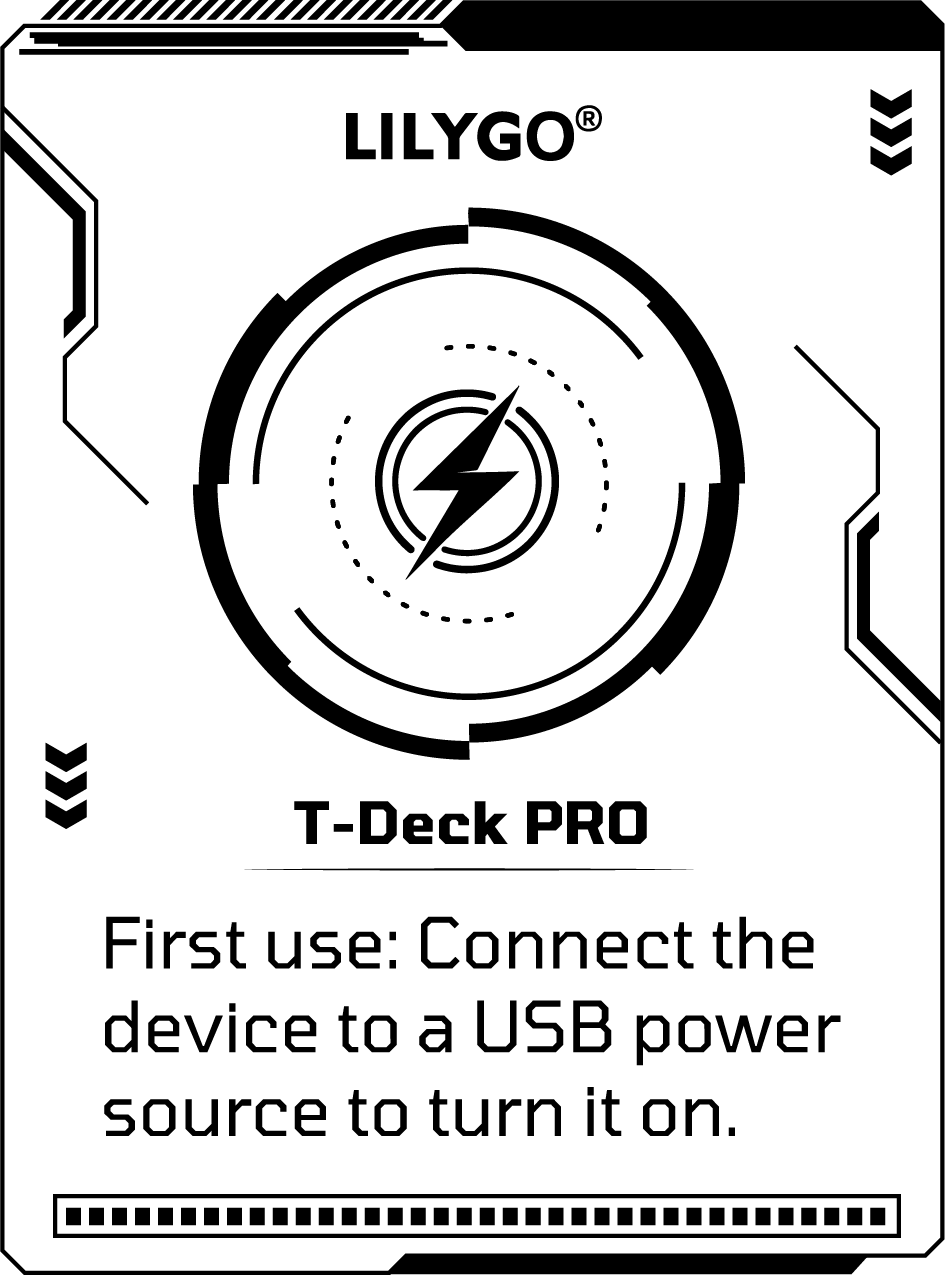
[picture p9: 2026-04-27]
docs/image_source/img_start.png

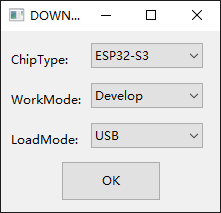
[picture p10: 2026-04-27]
docs/image.png

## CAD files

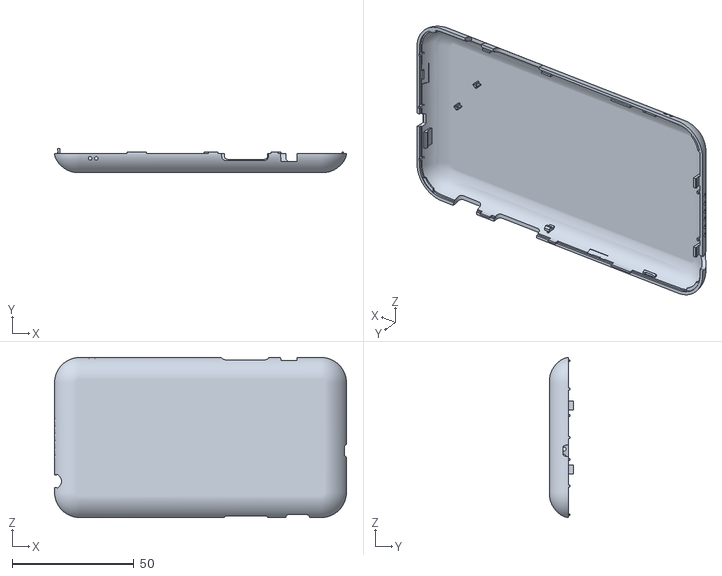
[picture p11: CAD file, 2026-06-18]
case/rear-cover-max.stl
120.1 x 9.80 x 65.9

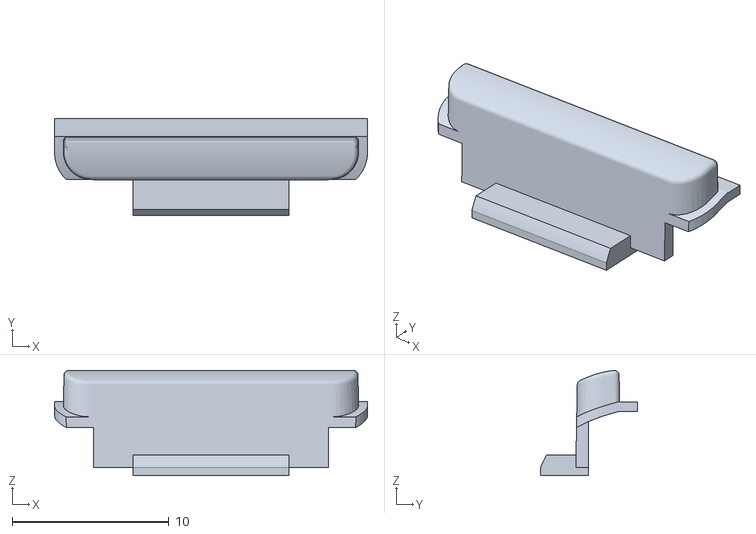
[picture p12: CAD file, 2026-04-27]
case/key.stl
20.0 x 6.21 x 6.72

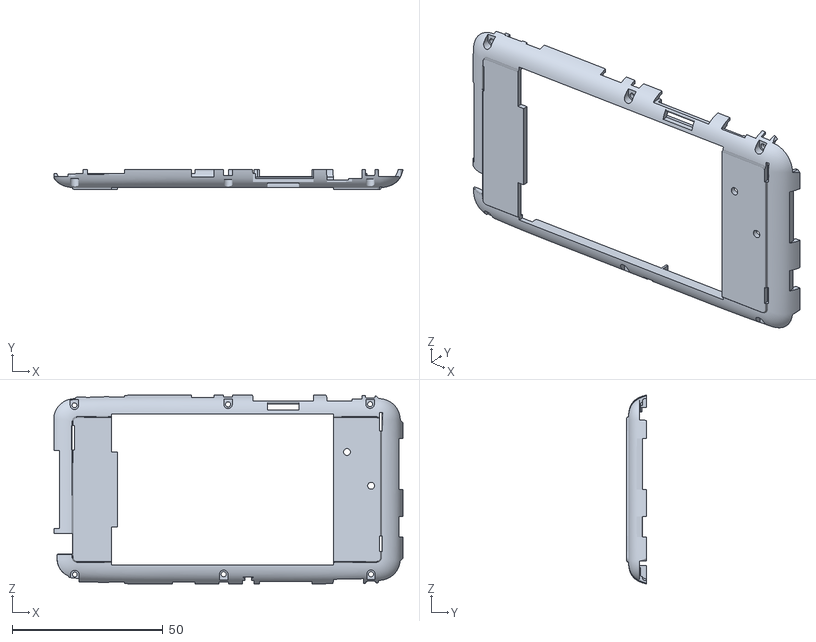
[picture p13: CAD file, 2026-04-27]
case/middle-bezel.stl
115.7 x 6.50 x 62.6

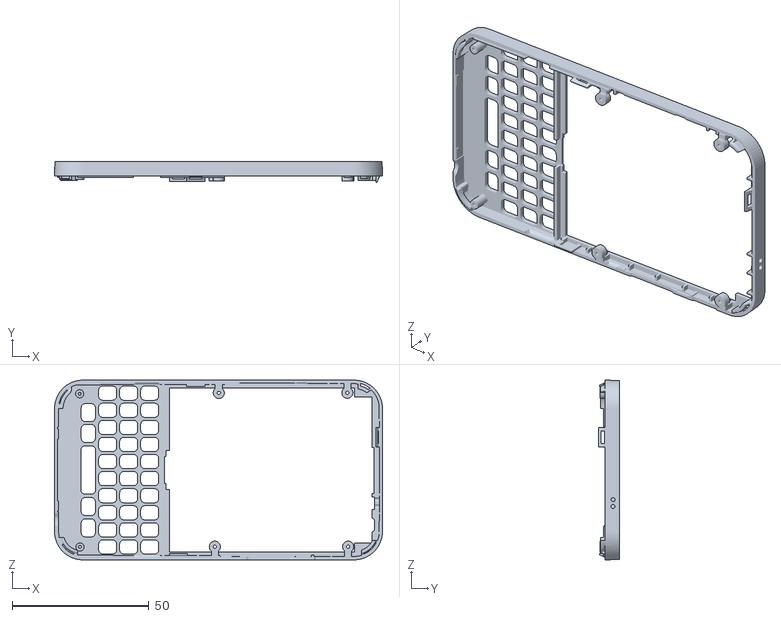
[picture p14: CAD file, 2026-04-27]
case/surface-covre.stl
120.1 x 7.60 x 65.9

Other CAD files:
case/rear-cover.stl

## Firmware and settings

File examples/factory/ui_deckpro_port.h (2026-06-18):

/************************************************************************
 * FilePath     : ui_base.h
 * Author       : GX.Duan
 * LastEditors  : ShallowGreen123 2608653986@qq.com
 * Copyright (c): 2022 by GX.Duan, All Rights Reserved.
 * Github       : https://github.com/ShallowGreen123/lvgl_examples.git
 ************************************************************************/
#ifndef __UI_PORT_DECKPOR_H__
#define __UI_PORT_DECKPOR_H__

/*********************************************************************************
 *                                  INCLUDES
 * *******************************************************************************/
#include "lvgl.h"
#include <WiFi.h>

#include "phone_runtime.h"
#include "peripheral.h"
#include "ui_deckpro.h"
#include "utilities.h"

#ifdef __cplusplus
extern "C" {
#endif
/*********************************************************************************
 *                                   DEFINES
 * *******************************************************************************/
// default language
#define DEFAULT_LANGUAGE_EN 0 // English
#define DEFAULT_LANGUAGE_CN 1 // Chinese

/*********************************************************************************
 *                                   MACROS
 * *******************************************************************************/

/*********************************************************************************
 *                                  TYPEDEFS
 * *******************************************************************************/

/*********************************************************************************
 *                              GLOBAL PROTOTYPES
 * *******************************************************************************/
void ui_disp_full_refr(void);
void ui_disp_partial_refr_for(uint32_t duration_ms);

// xl9555_io :
// BOARD_XL9555_00_6609_EN   
// BOARD_XL9555_01_LORA_EN   
// BOARD_XL9555_02_GPS_EN    
// BOARD_XL9555_03_1V8_EN    
// BOARD_XL9555_05_MOTOR_EN  
// BOARD_XL9555_10_PWRKEY_EN 
void ui_xl9555_power_on(int io);
void ui_xl9555_power_off(int io);

// Increase the volume of the speaker
// HIGH: Enable power amplifier
void ui_xl9555_amplifier(bool en);

/* LORA_SEL determines whether to use the internal antenna 
/  or the external antenna; Connected to XL9555 IO04
/   HIGH --- internal antenna
/   LOW --- external antenna  */
void ui_xl9555_lora_antenna_sel(bool ante);

/* Module A7682E and ES8311 share the output for headphones and speakers.
/  Select the audio output through AUDIO_SEL. When AUDIO_SEL is
/  HIGH : the headphones and speakers output the sound from A7682E.
/  LOW :  the headphones and speakers output the sound from ES8311. */
void ui_xl9555_audio_sel(bool sel);

// [ screen 1 ] --- lora
bool ui_lora_get_ante_dir(void);
void ui_lora_set_ante_dir(bool dir);
float ui_lora_get_freq(void);
void ui_lora_set_freq(float freq);
int ui_lora_get_bandwidth(void);
void ui_lora_set_bandwidth(float bd);
int ui_lora_get_power(void);
void ui_lora_set_power(float po);
void ui_lora_param_set(void);
int ui_lora_get_mode(void);
void ui_lora_set_mode(int mode);
void ui_lora_send(const char *str);
void ui_lora_recv_loop(void);
bool ui_lora_get_recv(const char **str, int *rssi);
void ui_lora_set_recv_flag(void);

// [ screen 2 ] --- setting
void ui_setting_set_language(int language);
void ui_setting_set_keypad_light(bool on);
void ui_setting_set_motor_status(bool on);
void ui_setting_set_gps_status(bool on);
void ui_setting_set_lora_status(bool on);
void ui_setting_set_gyro_status(bool on);
void ui_setting_set_a7682_status(bool on);

bool ui_setting_get_keypad_light(void);
bool ui_setting_get_motor_status(void);
bool ui_setting_get_gps_status(void);  
bool ui_setting_get_lora_status(void); 
bool ui_setting_get_gyro_status(void); 
bool ui_setting_get_a7682_status(void);

// setting - > About System
const char *ui_setting_get_sf_ver(void);
const char *ui_setting_get_hd_ver(void);
void ui_setting_get_sd_capacity(uint64_t *total, uint64_t *used);

// [ screen 3 ] --- GPS
void ui_gps_task_suspend(void);
void ui_gps_task_resume(void);
void ui_gps_get_coord(double *lat, double *lng);
void ui_gps_get_data(uint16_t *year, uint8_t *month, uint8_t *day);
void ui_gps_get_time(uint8_t *hour, uint8_t *minute, uint8_t *second);
void ui_gps_get_satellites(uint32_t *vsat);
void ui_gps_get_speed(double *speed);

// [ screen 4 ] --- Wifi Scan
void ui_wifi_get_scan_info(ui_wifi_scan_info_t *list, int list_len);
bool ui_wifi_connect(const char *ssid, const char *password);
wl_status_t ui_wifi_get_status(void);
void ui_wifi_disconnect(void);

// [ screen 5 ] --- State
bool ui_test_get(int peri_id);
bool ui_test_sd_card(void);
bool ui_test_a7682e(void);
bool ui_test_pcm5102(void);

// [ screen 6 ] --- Battery
/* 25896 */
bool ui_battery_25896_is_vbus_in(void);
bool ui_batt_25896_is_chg(void);
float ui_batt_25896_get_vbus(void);
float ui_batt_25896_get_vsys(void);
float ui_batt_25896_get_vbat(void);
float ui_batt_25896_get_volt_targ(void);
float ui_batt_25896_get_chg_curr(void);
float ui_batt_25896_get_pre_curr(void);
const char * ui_batt_25896_get_chg_st(void);
const char * ui_batt_25896_get_vbus_st(void);
const char * ui_batt_25896_get_ntc_st(void);

/* 27220 */
bool ui_battery_27220_is_vaild(void);
bool ui_battery_27220_get_input(void);
bool ui_battery_27220_get_charge_finish(void);
uint16_t ui_battery_27220_get_status(void);
uint16_t ui_battery_27220_get_voltage(void);
int16_t ui_battery_27220_get_current(void);
uint16_t ui_battery_27220_get_temperature(void);
uint16_t ui_battery_27220_get_full_capacity(void);
uint16_t ui_battery_27220_get_design_capacity(void);
uint16_t ui_battery_27220_get_remain_capacity(void);
uint16_t ui_battery_27220_get_percent(void);
uint16_t ui_battery_27220_get_health(void);
const char * ui_battert_27220_get_percent_level(void);

// [ screen 7 ] --- Input
int ui_input_get_touch_coord(int *x, int *y);
int ui_input_get_keypay_val(char *v);
int ui_input_get_keypay_event(char *v, int *state);
void ui_input_set_keypay_flag(void);
int ui_other_get_gyro(float *gyro_x, float *gyro_y, float *gyro_z);

// [ screen 8 ] --- Phone
bool ui_phone_dial(const char *number);
bool ui_phone_answer(void);
bool ui_phone_hang_up(void);
bool ui_phone_play_test_digits(void);
bool ui_phone_get_snapshot(ui_phone_snapshot_t *snapshot);
void ui_phone_set_debug_passthrough(bool enabled);

// shutdown
void ui_shutdown_on(void);

// [ screen 10 ] --- A7682E
bool ui_pcm5102_cb(const char *at_cmd);void ui_pcm5102_stop(void);
void ui_pcm5102_stop(void);

// [ screen 12 ] --- Motor
void ui_motor_loop(int i);
void ui_motor_stop(void);

//
void ui_system_sleep(void);

#ifdef __cplusplus
} /*extern "C"*/
#endif
#endif /* __UI_PORT_DECKPOR_H__ */

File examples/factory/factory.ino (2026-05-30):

/**
 * @file      test_touchpad.h
 * @author    ShallowGreen123
 * @license   MIT
 * @copyright Copyright (c) 2023  Shenzhen Xin Yuan Electronic Technology Co., Ltd
 * @date      2024-05-27
 *
 */


#include <Arduino.h>
#include "utilities.h"
#include <GxEPD2_BW.h>
#include <TouchDrvCSTXXX.hpp>
#include <TinyGPS++.h>
#include "lvgl.h"
#include "ui_deckpro.h"
#include <Fonts/FreeMonoBold9pt7b.h>
#include "factory.h"
#include "peripheral.h"
#include <SensorWireHelper.h>
#include <freertos/queue.h>
// #include "wav_hex.h"

#ifndef FACTORY_RUNTIME_LOG
#define FACTORY_RUNTIME_LOG 0
#endif

#define FACTORY_BATTERY_DESIGN_CAPACITY_MAH 1400

TinyGsm modem(SerialAT);
TaskHandle_t a7682_handle;

XPowersPPM PPM;
BQ27220 bq27220;

// TouchDrvCSTXXX touch;
GxEPD2_BW<GxEPD2_310_GDEQ031T10, GxEPD2_310_GDEQ031T10::HEIGHT> display(GxEPD2_310_GDEQ031T10(BOARD_EPD_CS, BOARD_EPD_DC, BOARD_EPD_RST, BOARD_EPD_BUSY)); // GDEQ031T10 240x320, UC8253, (no inking, backside mark KEGMO 3100)
ExtensionIOXL9555 xl9555_io;
Adafruit_DRV2605 motor_drv;
EspCodec codec;

uint8_t *decodebuffer = NULL;
int disp_refr_mode = DISP_REFR_MODE_PART;
static lv_disp_t *factory_disp = NULL;
static uint32_t disp_partial_refr_until_ms = 0;
const char HelloWorld[] = BOARD_NAME;

bool peri_init_st[E_PERI_NUM_MAX] = {0};

typedef enum {
    PHONE_CMD_DIAL = 0,
    PHONE_CMD_ANSWER,
    PHONE_CMD_HANGUP,
    PHONE_CMD_TEST_DIGITS,
    PHONE_CMD_DEBUG,
} phone_cmd_type_t;

typedef struct {
    phone_cmd_type_t type;
    char number[UI_PHONE_NUMBER_LEN];
    bool enabled;
} phone_cmd_t;

static QueueHandle_t phone_cmd_queue = NULL;
static portMUX_TYPE phone_snapshot_mux = portMUX_INITIALIZER_UNLOCKED;
static ui_phone_snapshot_t phone_snapshot = {};
static bool phone_audio_restore_valid = false;
static int phone_audio_restore_sel = HIGH;
static int phone_audio_restore_amp = HIGH;
static bool phone_call_connected = false;
static bool phone_call_incoming = false;
static bool phone_call_user_hangup = false;
static bool phone_clcc_query_pending = false;
static bool phone_clcc_lines_seen = false;
static volatile bool phone_test_audio_active = false;
static uint8_t phone_test_audio_ok_count = 0;
static uint32_t phone_call_start_ms = 0;
static uint32_t phone_state_started_ms = 0;
static uint32_t phone_test_audio_min_done_ms = 0;
static uint32_t phone_test_audio_restore_ms = 0;
static uint32_t phone_history_sequence = 0;
static char phone_end_reason[UI_PHONE_STATUS_LEN] = {0};

static void factory_touch_key_event(uint8_t key_id, bool pressed, void *user_data)
{
    (void)user_data;
    if (pressed && key_id < 3) {
        scr_mgr_pop(false);
    }
}

/*********************************************************************************
 *                              STATIC PROTOTYPES
 * *******************************************************************************/
static void epd_prepare_bus()
{
    // EPD, LoRa and SD share the SPI bus. Keep the other devices deselected
    // before sending commands to the panel to avoid command corruption.
    pinMode(BOARD_LORA_CS, OUTPUT);
    digitalWrite(BOARD_LORA_CS, HIGH);
    pinMode(BOARD_SD_CS, OUTPUT);
    digitalWrite(BOARD_SD_CS, HIGH);
    pinMode(BOARD_EPD_CS, OUTPUT);
    digitalWrite(BOARD_EPD_CS, HIGH);
}

static bool epd_area_is_full_screen(const lv_area_t *area)
{
    if (area == NULL) {
        return false;
    }

    return area->x1 <= 0 &&
           area->y1 <= 0 &&
           area->x2 >= (LCD_HOR_SIZE - 1) &&
           area->y2 >= (LCD_VER_SIZE - 1);
}

static uint32_t pack_lvgl_area_to_epd(const lv_color_t *color_p, uint32_t w, uint32_t h)
{
    const uint32_t bytes_per_row = (w + 7U) / 8U;
    uint32_t epd_idx = 0;

    for (uint32_t y = 0; y < h; ++y) {
        for (uint32_t x = 0; x < w; x += 8U) {
            uint8_t byte = 0;

            for (uint32_t bit = 0; bit < 8U; ++bit) {
                const uint32_t src_x = x + bit;
                if ((src_x < w) && color_p[(y * w) + src_x].full) {
                    byte |= (0x80U >> bit);
                }
            }

            decodebuffer[epd_idx++] = byte;
        }
    }

    return bytes_per_row * h;
}

static bool ink_screen_init()
{
    epd_prepare_bus();
    display.init(115200, true, 2, false);
    //Serial.println("helloWorld");
    display.setRotation(0);
    display.setFont(&FreeMonoBold9pt7b);
    if (display.epd2.WIDTH < 104) display.setFont(0);
    display.setTextColor(GxEPD_BLACK);
    int16_t tbx, tby; uint16_t tbw, tbh;
    display.getTextBounds(HelloWorld, 0, 0, &tbx, &tby, &tbw, &tbh);
    // center bounding box by transposition of origin:
    uint16_t x = ((display.width() - tbw) / 2) - tbx;
    uint16_t y = ((display.height() - tbh) / 2) - tby;
    display.setFullWindow();
    display.firstPage();
    do
    {
        display.fillScreen(GxEPD_WHITE);
        display.setCursor(x, y);
        display.print(HelloWorld);

        display.setCursor(x+35, y+30);
        display.print(UI_T_DECK_PRO_VERSION);
    }
    while (display.nextPage());
    display.powerOff();
    return true;
}

static void disp_flush(lv_disp_drv_t * disp_drv, const lv_area_t * area, lv_color_t * color_p)
{
    const uint32_t w = (uint32_t)(area->x2 - area->x1 + 1);
    const uint32_t h = (uint32_t)(area->y2 - area->y1 + 1);
    (void)pack_lvgl_area_to_epd(color_p, w, h);

    static int idx = 0;
    const bool full_window = epd_area_is_full_screen(area);

    epd_prepare_bus();
    // if(full_window) {
    //     display.setFullWindow();
    // } else {
    //     display.setPartialWindow(area->x1, area->y1, w, h);
    // }
    
    if(disp_refr_mode == DISP_REFR_MODE_PART) {
        display.setPartialWindow(area->x1, area->y1, w, h);
    } else if(disp_refr_mode == DISP_REFR_MODE_FULL){
        display.setFullWindow();
    }

    display.firstPage();
    do {
        display.drawInvertedBitmap(area->x1, area->y1, decodebuffer, w, h, GxEPD_BLACK);
    }
    while (display.nextPage());
    // display.hibernate();
    
#if FACTORY_RUNTIME_LOG
    Serial.printf("flush_timer_cb:%d, %s, x=%d, y=%d, w=%lu, h=%lu\n",
                  idx++,
                  (full_window ? "full" : "part"),
                  area->x1, area->y1,
                  (unsigned long)w, (unsigned long)h);
#else
    (void)idx;
#endif

    disp_refr_mode = DISP_REFR_MODE_PART;

    // Serial.printf("x1=%d, y1=%d, x2=%d, y2=%d\n", area->x1, area->y1, area->x2, area->y2);

    /*IMPORTANT!!!
     *Inform the graphics library that you are ready with the flushing*/
    lv_disp_flush_ready(disp_drv);
}

static void touchpad_read(lv_indev_drv_t * indev_drv, lv_indev_data_t * data)
{
    static lv_coord_t last_x = 0;
    static lv_coord_t last_y = 0;

    // uint8_t touched = touch.getPoint(&last_x, &last_y, 1);
    uint8_t touched = hyn_touch_get_point(&last_x, &last_y, 1);
    if(touched) {
        data->state = LV_INDEV_STATE_PR;

#if FACTORY_RUNTIME_LOG
        Serial.printf("x = %d, y = %d\n", last_x, last_y);
#endif
    } else {
        data->state = LV_INDEV_STATE_REL;
    }
    /*Set the last pressed coordinates*/
    data->point.x = last_x;
    data->point.y = last_y;
}

static void lvgl_init(void)
{
    lv_init();

    static lv_disp_draw_buf_t draw_buf_dsc_1;
    lv_color_t *buf_1 = (lv_color_t *)ps_calloc(sizeof(lv_color_t), DISP_BUF_SIZE);
    lv_color_t *buf_2 = (lv_color_t *)ps_calloc(sizeof(lv_color_t), DISP_BUF_SIZE);
    lv_disp_draw_buf_init(&draw_buf_dsc_1, buf_1, buf_2, LCD_HOR_SIZE * LCD_VER_SIZE);
    decodebuffer = (uint8_t *)ps_calloc(sizeof(uint8_t), DISP_BUF_SIZE);
    // lv_disp_draw_buf_init(&draw_buf, lv_disp_buf_p, NULL, DISP_BUF_SIZE);

    static lv_disp_drv_t disp_drv;
    lv_disp_drv_init(&disp_drv);
    disp_drv.hor_res = LCD_HOR_SIZE;
    disp_drv.ver_res = LCD_VER_SIZE;
    disp_drv.flush_cb = disp_flush;
    // disp_drv.render_start_cb = dips_render_start_cb;
    disp_drv.draw_buf = &draw_buf_dsc_1;
    // disp_drv.rounder_cb = display_driver_rounder_cb;
    disp_drv.full_refresh = 1;

    factory_disp = lv_disp_drv_register(&disp_drv);

    /*------------------
     * Touchpad
     * -----------------*/
    /*Register a touchpad input device*/
    static lv_indev_drv_t indev_drv;
    lv_indev_drv_init(&indev_drv);
    indev_drv.type = LV_INDEV_TYPE_POINTER;
    indev_drv.read_cb = touchpad_read;
    lv_indev_drv_register(&indev_drv);
}

static bool bq25896_init(void)
{
    int ret = 0;
    // BQ25896 --- 0x6B
    // ret = Wire.beginTransmission(BOARD_I2C_ADDR_BQ25896);
    // ret = Wire.endTransmission();
    // if (ret == 0)
    // {
    //     // battery_25896.begin();
    //     PPM.init(Wire, BOARD_I2C_SDA, BOARD_I2C_SCL, BOARD_I2C_ADDR_BQ25896);
    //     // set battery charge voltage
    //     PPM.setChargeTargetVoltage(4288);

    //     // Set charge current
    //     PPM.setChargerConstantCurr(1024);

    //     // Enable measure
    //     // PPM.enableMeasure();
    //     PPM.disableMeasure();

    //     return true;
    // }

    // SY6970 --- 0x6A
    Wire.beginTransmission(SY6970_SLAVE_ADDRESS);
    ret = Wire.endTransmission();
    if(ret == 0) {
        PPM.init(Wire, BOARD_I2C_SDA, BOARD_I2C_SCL, SY6970_SLAVE_ADDRESS);
        // set battery charge voltage
        PPM.setChargeTargetVoltage(4288);

        // Set charge current
        PPM.setChargerConstantCurr(1024);

        // Enable measure
        // PPM.enableMeasure();
        PPM.disableADCMeasure();

        return true;
    }
    return false;
}

static bool bq27220_init(void)
{
    bq27220.setDefaultCapacity(FACTORY_BATTERY_DESIGN_CAPACITY_MAH);
    bool ret = bq27220.init();
    // if(ret) 
    //     bq27220.reset();
    return ret;
}

static bool sd_care_init(void)
{
    if(!SD.begin(BOARD_SD_CS)){
        Serial.println("[SD CARD] Card Mount Failed");
        return false;
    }

    uint64_t cardSize = SD.cardSize() / (1024 * 1024);
    Serial.printf("SD Card Size: %lluMB\n", cardSize);

    uint64_t totalSize = SD.totalBytes() / (1024 * 1024);
    Serial.printf("SD Card Total: %lluMB\n", totalSize);

    uint64_t usedSize = SD.usedBytes() / (1024 * 1024);
    Serial.printf("SD Card Used: %lluMB\n", usedSize);
    return true;
}

static void phone_copy_text(char *dst, size_t dst_len, const char *src)
{
    if (dst == NULL || dst_len == 0U) {
        return;
    }

    if (src == NULL) {
        dst[0] = '\0';
        return;
    }

    strncpy(dst, src, dst_len - 1U);
    dst[dst_len - 1U] = '\0';
}

static void phone_snapshot_reset(bool available)
{
    portENTER_CRITICAL(&phone_snapshot_mux);
    memset(&phone_snapshot, 0, sizeof(phone_snapshot));
    phone_snapshot.state = available ? UI_PHONE_STATE_IDLE : UI_PHONE_STATE_UNAVAILABLE;
    phone_copy_text(phone_snapshot.status, sizeof(phone_snapshot.status), available ? "Idle" : "A7682E Failed");
    phone_snapshot.debug_passthrough = false;
    portEXIT_CRITICAL(&phone_snapshot_mux);

    phone_audio_restore_valid = false;
    phone_call_connected = false;
    phone_call_incoming = false;
    phone_call_user_hangup = false;
    phone_clcc_query_pending = false;
    phone_clcc_lines_seen = false;
    phone_test_audio_active = false;
    phone_test_audio_ok_count = 0;
    phone_call_start_ms = 0;
    phone_state_started_ms = 0;
    phone_test_audio_min_done_ms = 0;
    phone_test_audio_restore_ms = 0;
    phone_history_sequence = 0;
    memset(phone_end_reason, 0, sizeof(phone_end_reason));
}

static ui_phone_state_t phone_snapshot_state(void)
{
    ui_phone_state_t state;
    portENTER_CRITICAL(&phone_snapshot_mux);
    state = phone_snapshot.state;
    portEXIT_CRITICAL(&phone_snapshot_mux);
    return state;
}

static void phone_snapshot_set_debug(bool enabled)
{
    portENTER_CRITICAL(&phone_snapshot_mux);
    phone_snapshot.debug_passthrough = enabled;
    if (phone_snapshot.state == UI_PHONE_STATE_IDLE) {
        phone_copy_text(phone_snapshot.status, sizeof(phone_snapshot.status), enabled ? "AT Debug" : "Idle");
    }
    portEXIT_CRITICAL(&phone_snapshot_mux);
}

static void phone_snapshot_set_state(ui_phone_state_t state, const char *number, const char *status)
{
    portENTER_CRITICAL(&phone_snapshot_mux);
    phone_snapshot.state = state;
    phone_snapshot.debug_passthrough = false;
    if (number != NULL) {
        phone_copy_text(phone_snapshot.current_number, sizeof(phone_snapshot.current_number), number);
    }
    if (status != NULL) {
        phone_copy_text(phone_snapshot.status, sizeof(phone_snapshot.status), status);
    }
    portEXIT_CRITICAL(&phone_snapshot_mux);
}

static void phone_snapshot_set_number(const char *number)
{
    portENTER_CRITICAL(&phone_snapshot_mux);
    phone_copy_text(phone_snapshot.current_number, sizeof(phone_snapshot.current_number), number);
    portEXIT_CRITICAL(&phone_snapshot_mux);
}

static void phone_snapshot_add_history(const char *direction, const char *result, const char *number)
{
    if (number == NULL || number[0] == '\0') {
        return;
    }

    portENTER_CRITICAL(&phone_snapshot_mux);
    for (int i = UI_PHONE_HISTORY_MAX - 1; i > 0; --i) {
        phone_snapshot.recent_calls[i] = phone_snapshot.recent_calls[i - 1];
    }

    memset(&phone_snapshot.recent_calls[0], 0, sizeof(phone_snapshot.recent_calls[0]));
    phone_copy_text(phone_snapshot.recent_calls[0].number, sizeof(phone_snapshot.recent_calls[0].number), number);
    phone_copy_text(phone_snapshot.recent_calls[0].direction, sizeof(phone_snapshot.recent_calls[0].direction), direction);
    phone_copy_text(phone_snapshot.recent_calls[0].result, sizeof(phone_snapshot.recent_calls[0].result), result);
    phone_snapshot.recent_calls[0].sequence = ++phone_history_sequence;
    portEXIT_CRITICAL(&phone_snapshot_mux);
}

static void phone_capture_audio_state(void)
{
    if (phone_audio_restore_valid) {
        return;
    }

    phone_audio_restore_sel = xl9555_io.digitalRead(BOARD_XL9555_12_AUDIO_SEL);
    phone_audio_restore_amp = xl9555_io.digitalRead(BOARD_XL9555_06_AMPLIFIER);
    phone_audio_restore_valid = true;
}

static void phone_enable_call_audio(void)
{
    phone_capture_audio_state();
    xl9555_io.digitalWrite(BOARD_XL9555_12_AUDIO_SEL, HIGH);
    xl9555_io.digitalWrite(BOARD_XL9555_06_AMPLIFIER, HIGH);
}

static void phone_restore_audio(void)
{
    if (!phone_audio_restore_valid) {
        return;
    }

    xl9555_io.digitalWrite(BOARD_XL9555_12_AUDIO_SEL, phone_audio_restore_sel);
    xl9555_io.digitalWrite(BOARD_XL9555_06_AMPLIFIER, phone_audio_restore_amp);
    phone_audio_restore_valid = false;
}

static void phone_reset_call_session(void)
{
    phone_call_connected = false;
    phone_call_incoming = false;
    phone_call_user_hangup = false;
    phone_clcc_query_pending = false;
    phone_clcc_lines_seen = false;
    phone_call_start_ms = 0;
    phone_state_started_ms = 0;
    memset(phone_end_reason, 0, sizeof(phone_end_reason));
}

static void phone_set_end_reason(const char *reason)
{
    phone_copy_text(phone_end_reason, sizeof(phone_end_reason), reason);
}

static const char *phone_choose_end_reason(void)
{
    if (phone_end_reason[0] != '\0') {
        return phone_end_reason;
    }

    if (phone_call_incoming && !phone_call_connected) {
        return phone_call_user_hangup ? "Rejected" : "Missed";
    }

    if (!phone_call_incoming && !phone_call_connected) {
        return phone_call_user_hangup ? "Canceled" : "Ended";
    }

    return "Ended";
}

static void phone_begin_outgoing_call(const char *number)
{
    phone_reset_call_session();
    phone_enable_call_audio();
    phone_call_incoming = false;
    phone_state_started_ms = millis();
    phone_snapshot_set_state(UI_PHONE_STATE_OUTGOING, number, "Dialing");
}

static void phone_begin_incoming_call(const char *number)
{
    if (phone_snapshot_state() == UI_PHONE_STATE_ACTIVE) {
        return;
    }

    phone_reset_call_session();
    phone_enable_call_audio();
    phone_call_incoming = true;
    phone_state_started_ms = millis();
    phone_snapshot_set_state(UI_PHONE_STATE_INCOMING, number, "Incoming");
}

static void phone_mark_active_call(const char *number)
{
    if (!phone_call_connected) {
        phone_call_connected = true;
        phone_call_start_ms = millis();
    }

    phone_state_started_ms = millis();
    phone_enable_call_audio();
    phone_snapshot_set_state(UI_PHONE_STATE_ACTIVE, number, "In Call");
}

static void phone_finalize_call(const char *result)
{
    char number[UI_PHONE_NUMBER_LEN] = {0};
    const char *direction = phone_call_incoming ? "Incoming" : "Outgoing";

    portENTER_CRITICAL(&phone_snapshot_mux);
    phone_copy_text(number, sizeof(number), phone_snapshot.current_number);
    portEXIT_CRITICAL(&phone_snapshot_mux);

    if (number[0] != '\0') {
        phone_snapshot_add_history(direction, result, number);
    }

    phone_restore_audio();
    phone_reset_call_session();
    phone_snapshot_set_state(UI_PHONE_STATE_IDLE, "", "Idle");
}

static void phone_finish_test_audio(void)
{
    if (!phone_test_audio_active) {
        return;
    }

    phone_restore_audio();
    phone_test_audio_active = false;
    phone_test_audio_ok_count = 0;
    phone_test_audio_min_done_ms = 0;
    phone_test_audio_restore_ms = 0;
    phone_snapshot_set_state(UI_PHONE_STATE_IDLE, NULL, "Idle");
}

static bool phone_queue_command(phone_cmd_type_t type, const char *number, bool enabled)
{
    if (phone_cmd_queue == NULL) {
        return false;
    }

    phone_cmd_t cmd = {};
    cmd.type = type;
    cmd.enabled = enabled;
    if (number != NULL) {
        phone_copy_text(cmd.number, sizeof(cmd.number), number);
    }
    return xQueueSend(phone_cmd_queue, &cmd, 0) == pdPASS;
}

bool phone_runtime_dial(const char *number)
{
    if (number == NULL || number[0] == '\0') {
        return false;
    }

    if (phone_snapshot_state() != UI_PHONE_STATE_IDLE || phone_test_audio_active) {
        return false;
    }

    return phone_queue_command(PHONE_CMD_DIAL, number, false);
}

bool phone_runtime_answer(void)
{
    return phone_snapshot_state() == UI_PHONE_STATE_INCOMING &&
           phone_queue_command(PHONE_CMD_ANSWER, NULL, false);
}

bool phone_runtime_hang_up(void)
{
    ui_phone_state_t state = phone_snapshot_state();
    if (state != UI_PHONE_STATE_INCOMING &&
        state != UI_PHONE_STATE_OUTGOING &&
        state != UI_PHONE_STATE_ACTIVE) {
        return false;
    }

    return phone_queue_command(PHONE_CMD_HANGUP, NULL, false);
}

bool phone_runtime_play_test_digits(void)
{
    if (phone_snapshot_state() != UI_PHONE_STATE_IDLE || phone_test_audio_active) {
        return false;
    }

    phone_test_audio_active = true;
    phone_test_audio_ok_count = 0;
    phone_snapshot_set_state(UI_PHONE_STATE_IDLE, NULL, "Testing 0-9");
    if (!phone_queue_command(PHONE_CMD_TEST_DIGITS, NULL, false)) {
        phone_snapshot_set_state(UI_PHONE_STATE_IDLE, NULL, "Idle");
        phone_test_audio_active = false;
        phone_test_audio_ok_count = 0;
        return false;
    }
    return true;
}

void phone_runtime_set_debug_passthrough(bool enabled)
{
    if (!enabled) {
        phone_snapshot_set_debug(false);
    }

    if (phone_cmd_queue == NULL) {
        return;
    }

    if (!enabled || (phone_snapshot_state() == UI_PHONE_STATE_IDLE && !phone_test_audio_active)) {
        (void)phone_queue_command(PHONE_CMD_DEBUG, NULL, enabled);
    }
}

bool phone_runtime_get_snapshot(ui_phone_snapshot_t *snapshot)
{
    if (snapshot == NULL) {
        return false;
    }

    portENTER_CRITICAL(&phone_snapshot_mux);
    *snapshot = phone_snapshot;
    if (phone_snapshot.state == UI_PHONE_STATE_ACTIVE && phone_call_start_ms > 0U) {
        snapshot->call_duration_sec = (millis() - phone_call_start_ms) / 1000U;
    } else {
        snapshot->call_duration_sec = 0;
    }
    portEXIT_CRITICAL(&phone_snapshot_mux);

    if (snapshot->status[0] == '\0') {
        phone_copy_text(snapshot->status, sizeof(snapshot->status),
                        snapshot->state == UI_PHONE_STATE_UNAVAILABLE ? "A7682E Failed" : "Idle");
    }
    return true;
}

static void phone_send_command_line(const char *line)
{
    if (line == NULL || line[0] == '\0') {
        return;
    }

    SerialAT.print(line);
    SerialAT.print("\r\n");
}

static void phone_send_dial_command(const char *number)
{
    SerialAT.print("ATD");
    SerialAT.print(number);
    SerialAT.print(";\r\n");
}
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
void loop()
{
    lv_task_handler();
    keypad_loop();

    if (disp_partial_refr_until_ms > 0U &&
        millis() >= disp_partial_refr_until_ms) {
        lv_disp_t *disp = factory_disp ? factory_disp : lv_disp_get_default();
        if (disp != NULL && disp->driver != NULL) {
            disp->driver->full_refresh = 1;
        }
        disp_partial_refr_until_ms = 0U;
    }

    delay(1);
}

/*********************************************************************************
 *                              GLOBAL PROTOTYPES
 * *******************************************************************************/
void disp_full_refr(void)
{
    lv_disp_t *disp = factory_disp ? factory_disp : lv_disp_get_default();
    if (disp != NULL && disp->driver != NULL) {
        disp->driver->full_refresh = 1;
    }
    disp_partial_refr_until_ms = 0U;
    disp_refr_mode = DISP_REFR_MODE_FULL;
}

void disp_partial_refr_for(uint32_t duration_ms)
{
    lv_disp_t *disp = factory_disp ? factory_disp : lv_disp_get_default();
    if (disp != NULL && disp->driver != NULL) {
        disp->driver->full_refresh = 0;
    }
    disp_refr_mode = DISP_REFR_MODE_PART;
    disp_partial_refr_until_ms = millis() + duration_ms;
}

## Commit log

2026-05-22 Add attachments and documents
2026-05-22 Update the document and correct the spelling mistakes.
    [eng_test.ino, eng_test_runtime.cpp, factory.ino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]
2026-05-25 Pin headers consolidated into a single common header file
2026-06-18 Add the STL file of the Max rear cover #4
    [rear-cover-max.stl]
2026-06-18 Resolve the issues described in #2 and #3
    ALT = abc/ABC
    Hold UP = chars
    ENT = OK
    DEL = erase/clear
    SYM = show/back
    [peri_keypad.cpp, ui_deckpro.cpp, ui_deckpro_port.cpp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]
2026-10-12 global: fix GYROSCOPDE typo
2026-10-12 ui: fix modem and motor power toggle
2026-10-12 ui: fix power gating for gps/lora/gyro
